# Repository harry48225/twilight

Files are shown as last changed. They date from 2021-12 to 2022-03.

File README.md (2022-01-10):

# ```twlight```

An automated roller blind opener. Using an esp32 runing micropython.

## ```twilight.local```
The esp32 serves a svelte webapp on ``` twilight.local```. See ```firmware/webapp```
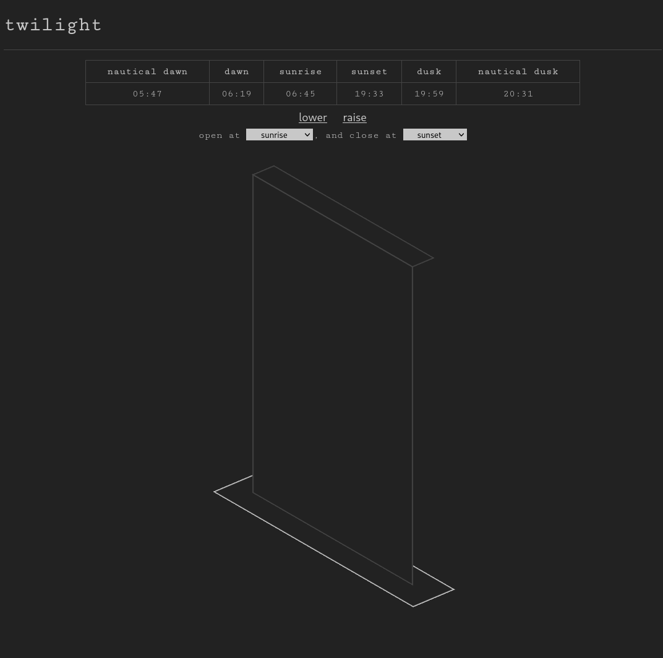
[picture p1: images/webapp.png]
webapp


## ```hardware```
A NEMA 17 stepper motor is used to move the blinds. It's connected to a 3d-printed gearbox ```cad/``` providing an ~1:5 reduction. It's driven by a DRV8825 stepper motor driver.
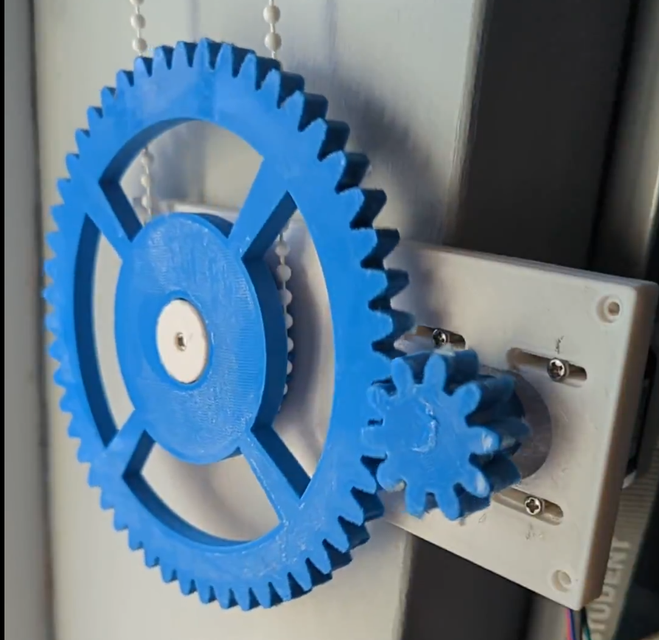
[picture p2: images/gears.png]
gears


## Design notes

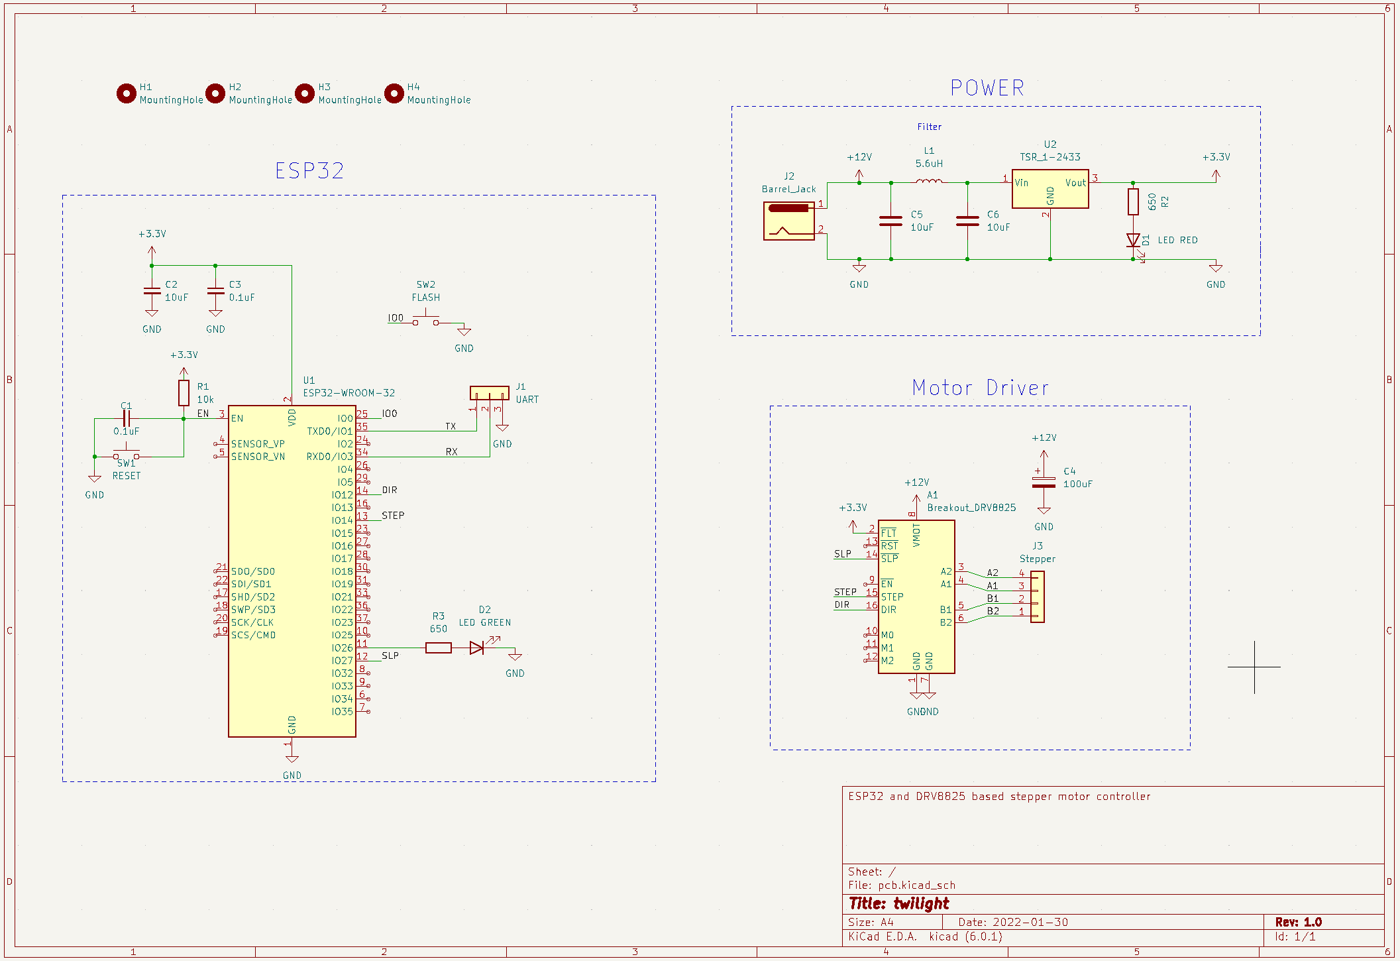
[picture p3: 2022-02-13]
pcb/pcb/schematic.png

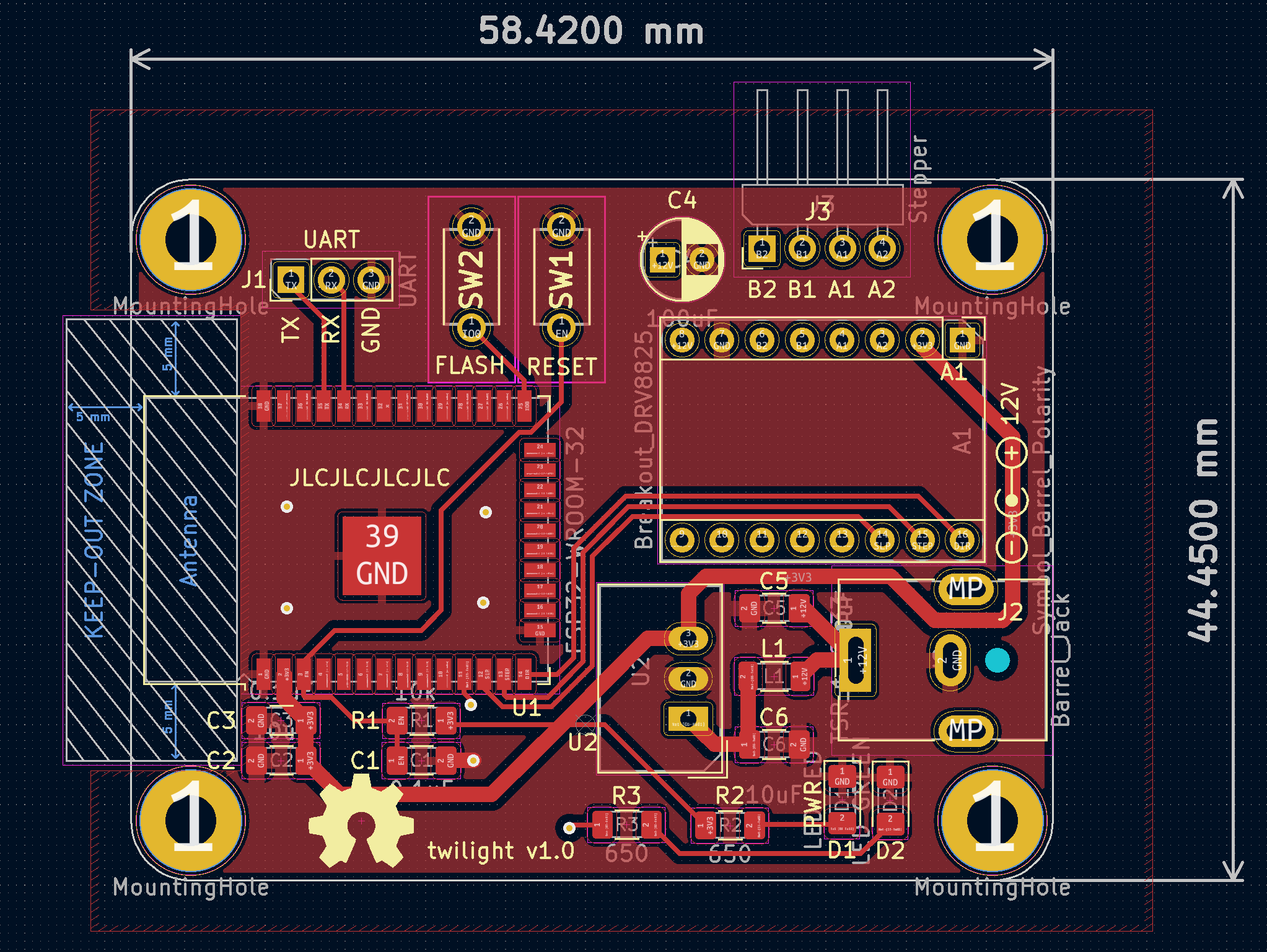
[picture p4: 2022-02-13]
pcb/pcb/pcbtop.png

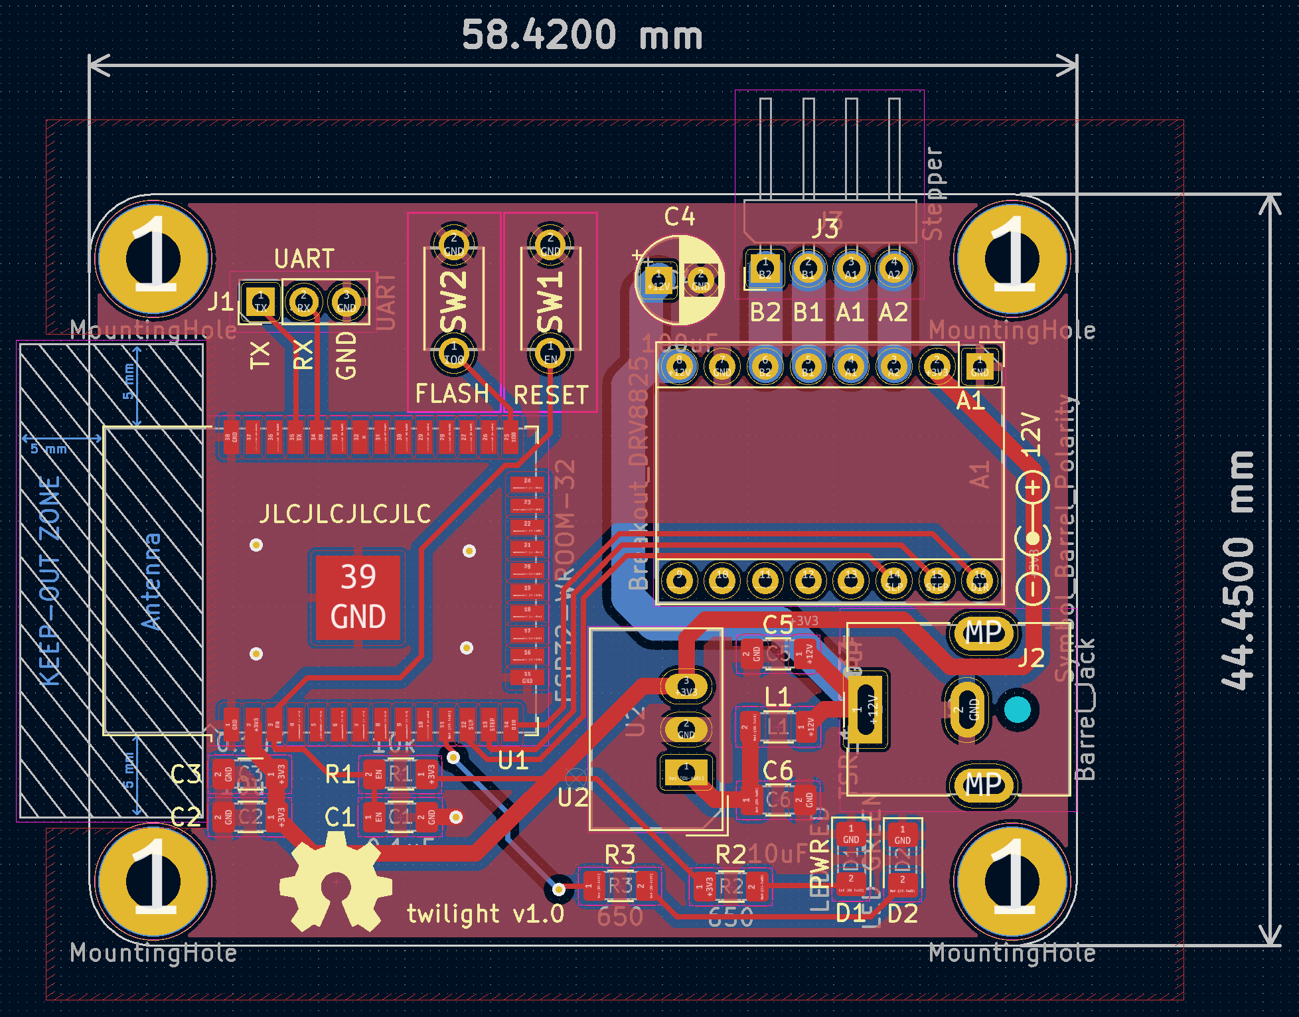
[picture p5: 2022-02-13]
pcb/pcb/fullpcb.png

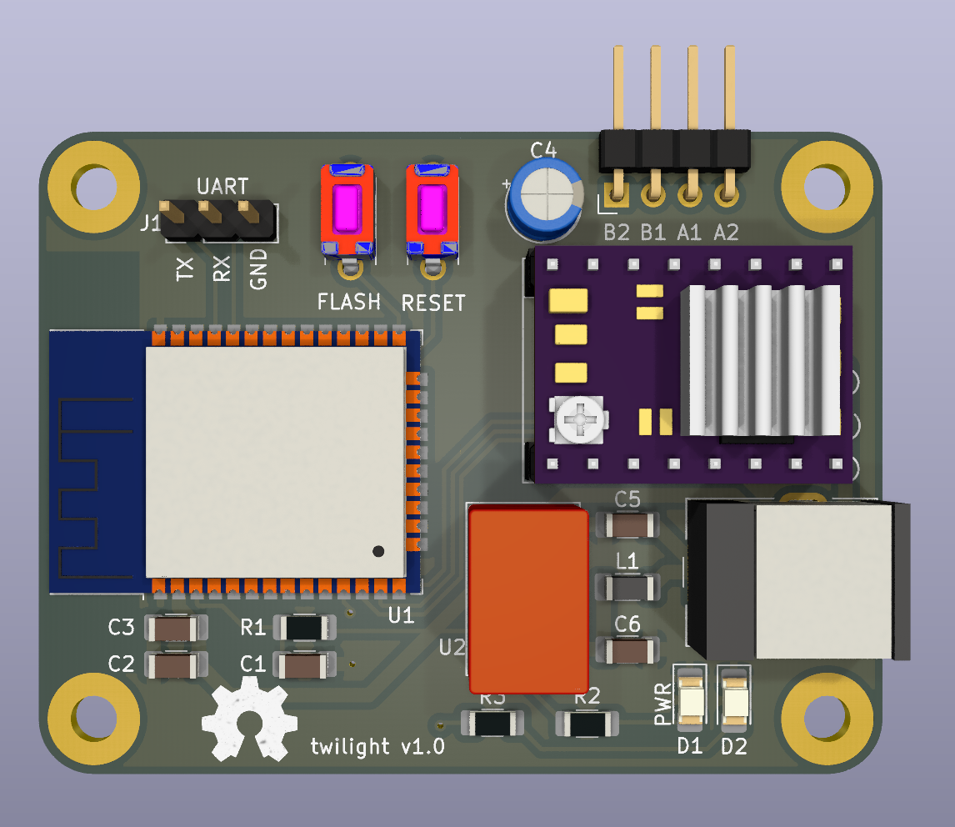
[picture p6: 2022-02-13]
pcb/pcb/3d render.png

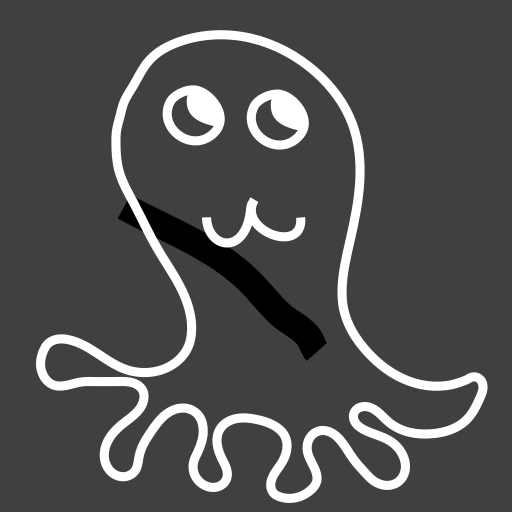
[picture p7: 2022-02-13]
pcb/octopus.png

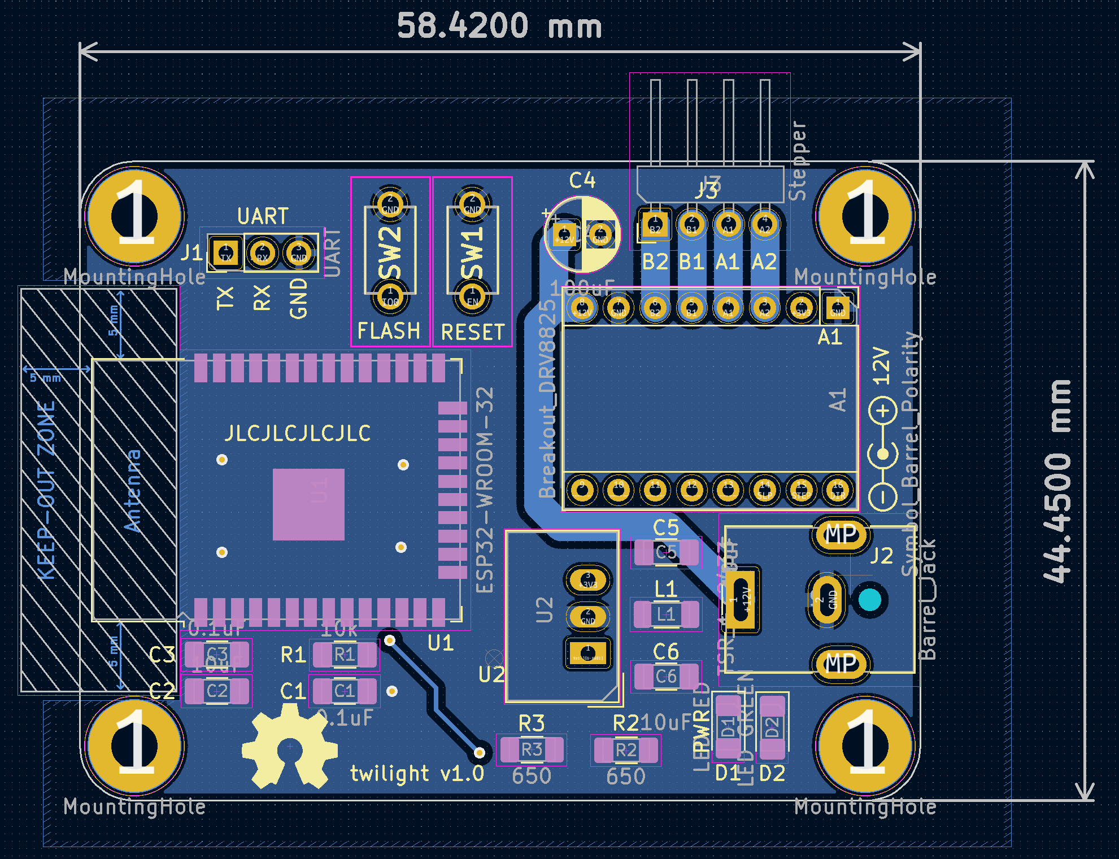
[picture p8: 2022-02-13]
pcb/pcb/pcbbottom.png

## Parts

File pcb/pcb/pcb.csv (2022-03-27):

Source: | /home/harry/Documents/twilight/pcb/pcb/pcb.kicad_sch
Date: | Fri 04 Mar 2022 14:39:49 GMT
Tool: | Eeschema (6.0.2)
Generator: | /usr/share/kicad/plugins/bom_csv_grouped_by_value_with_fp.py
Component Count: | 24
Ref | Qnty | Value | Cmp name | Footprint | Description | Vendor
A1, | 1 | Breakout_DRV8825 | Pololu_Breakout_DRV8825 | Module:Pololu_Breakout-16_15.2x20.3mm | Pololu Breakout Board, Stepper Driver DRV8825
C1, C3, | 2 | 0.1uF | C_Small | Capacitor_SMD:C_1206_3216Metric_Pad1.33x1.80mm_HandSolder | Unpolarized capacitor, small symbol
C2, C5, C6, | 3 | 10uF | C | Capacitor_SMD:C_1206_3216Metric_Pad1.33x1.80mm_HandSolder | Unpolarized capacitor
C4, | 1 | 100uF | C_Polarized | Capacitor_THT:CP_Radial_D5.0mm_P2.50mm | Polarized capacitor
D1, | 1 | LED RED | LED | LED_SMD:LED_1206_3216Metric_Pad1.42x1.75mm_HandSolder | Light emitting diode
D2, | 1 | LED GREEN | LED | LED_SMD:LED_1206_3216Metric_Pad1.42x1.75mm_HandSolder | Light emitting diode
H1, H3, | 2 | MountingHole | MountingHole | MountingHole:MountingHole_3.2mm_M3 | Mounting Hole without connection
H2, H4, | 2 | MountingHole | MountingHole | MountingHole:MountingHole_3.2mm_M3_Pad | Mounting Hole without connection
J1, | 1 | UART | Conn_01x03 | Connector_PinHeader_2.54mm:PinHeader_1x03_P2.54mm_Vertical | Generic connector, single row, 01x03, script generated (kicad-library-utils/schlib/autogen/connector/)
J2, | 1 | Barrel_Jack | Barrel_Jack | Connector_BarrelJack:BarrelJack_CUI_PJ-063AH_Horizontal | DC Barrel Jack
J3, | 1 | Stepper | Conn_01x04 | Connector_PinHeader_2.54mm:PinHeader_1x04_P2.54mm_Horizontal | Generic connector, single row, 01x04, script generated (kicad-library-utils/schlib/autogen/connector/)
L1, | 1 | 5.6uH | L | Inductor_SMD:L_TracoPower_TCK-141 | Inductor
R1, | 1 | 10k | R | Resistor_SMD:R_1206_3216Metric_Pad1.30x1.75mm_HandSolder | Resistor
R2, R3, | 2 | 650 | R | Resistor_SMD:R_1206_3216Metric_Pad1.30x1.75mm_HandSolder | Resistor
SW1, | 1 | RESET | SW_Push | buttons:PTS636SK43LFS | Push button switch, generic, two pins
SW2, | 1 | FLASH | SW_Push | buttons:PTS636SK43LFS | Push button switch, generic, two pins
U1, | 1 | ESP32-WROOM-32 | ESP32-WROOM-32 | RF_Module:ESP32-WROOM-32 | RF Module, ESP32-D0WDQ6 SoC, Wi-Fi 802.11b/g/n, Bluetooth, BLE, 32-bit, 2.7-3.6V, onboard antenna, SMD
U2, | 1 | TSR_1-2433 | TSR_1-2433 | Converter_DCDC:Converter_DCDC_TRACO_TSR-1_THT | 1A step-down regulator module, fixed 3.3V output voltage, 5-36V input voltage, -40°C to +85°C temperature range, TO-220 compatible LM78xx replacement

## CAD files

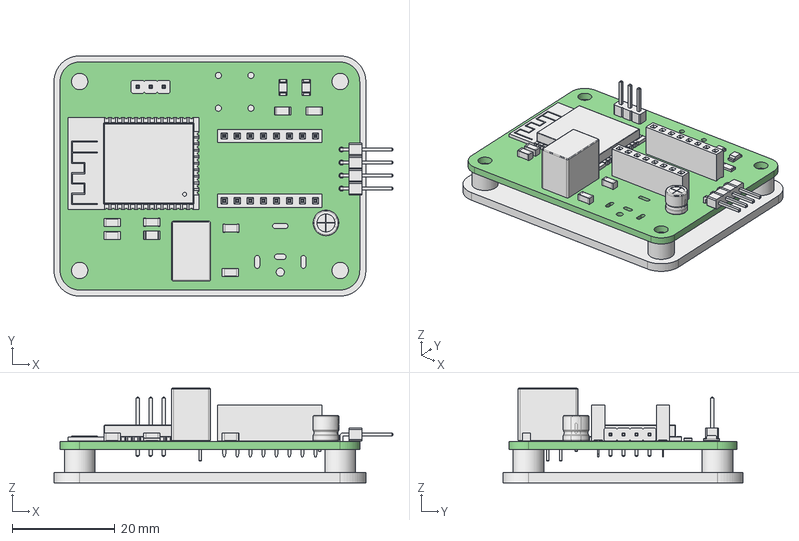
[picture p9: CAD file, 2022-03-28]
cad/pcb mount.FCStd
66.1 x 46.8 x 18.5 mm
pcb PCB

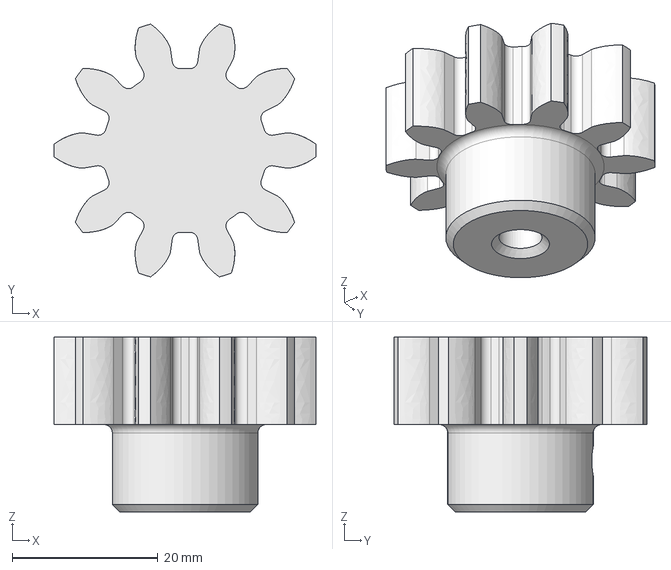
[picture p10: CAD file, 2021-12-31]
cad/small gear.FCStd
36.0 x 34.7 x 24.0 mm

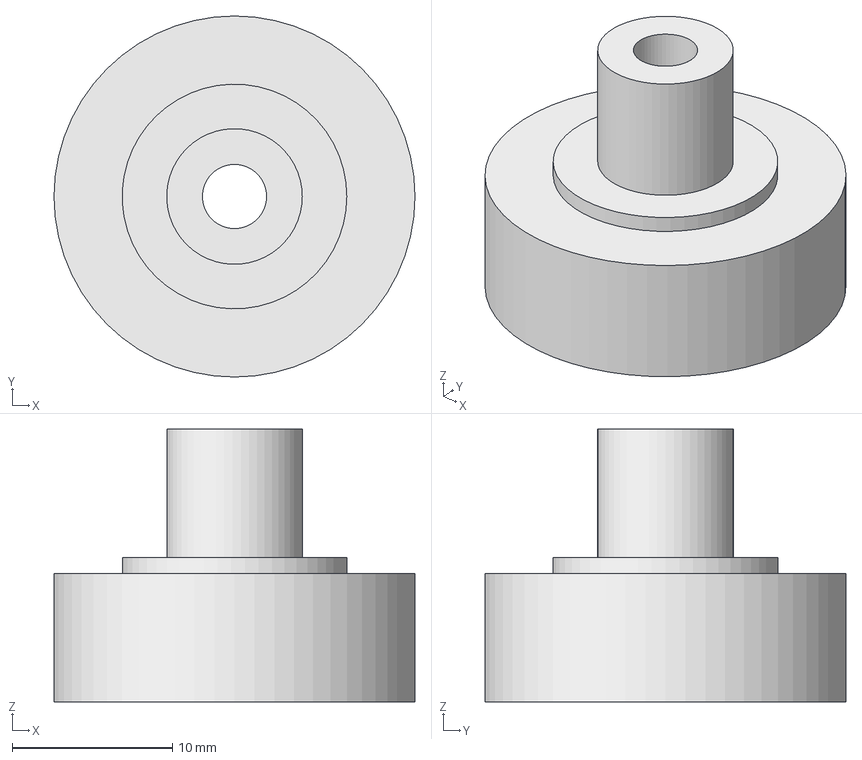
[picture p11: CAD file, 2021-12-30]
cad/large gear shaft.FCStd
22.5 x 22.5 x 17.0 mm

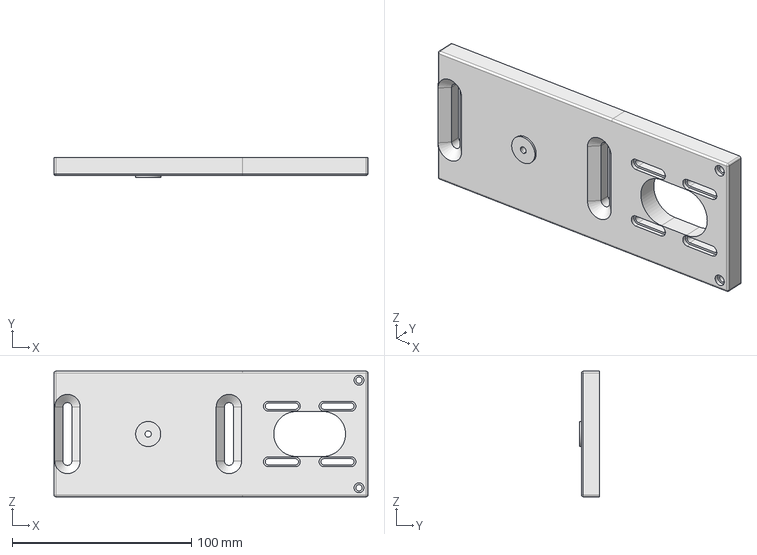
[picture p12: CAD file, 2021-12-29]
cad/wall plate.FCStd
175.0 x 11.0 x 70.0 mm

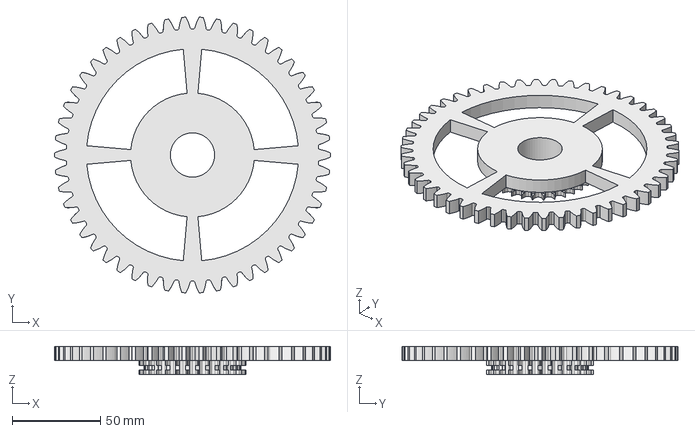
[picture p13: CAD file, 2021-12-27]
cad/blindGear.FCStd
156.0 x 155.8 x 16.0 mm

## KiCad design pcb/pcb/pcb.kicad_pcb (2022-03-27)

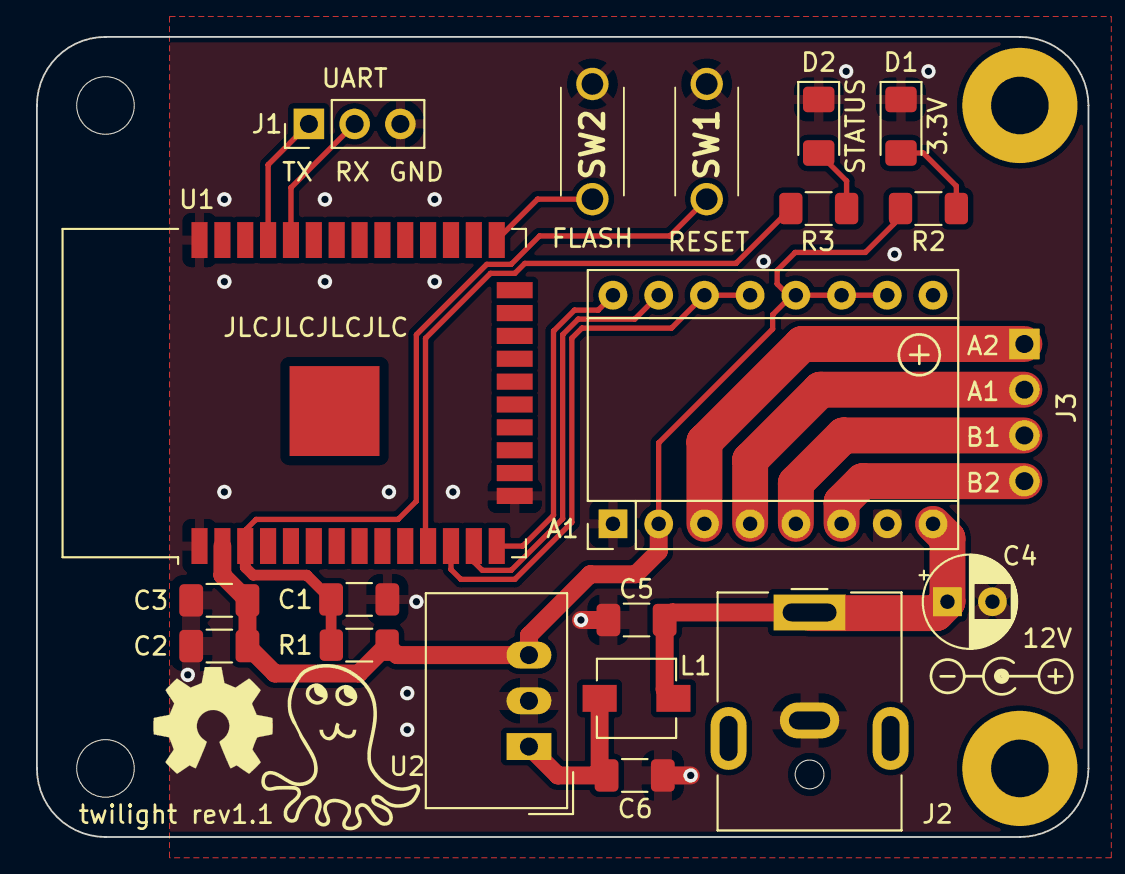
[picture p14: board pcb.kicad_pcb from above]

Board: 2 copper layers, 58.4 x 44.4 mm, 24 parts (0 on the bottom side), 18 nets.

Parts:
A1: Breakout_DRV8825; Pololu_Breakout-16_15.2x20.3mm
C1, C3: 0.1uF; C_1206_3216Metric_Pad1.33x1.80mm_HandSolder
C2, C5, C6: 10uF; C_1206_3216Metric_Pad1.33x1.80mm_HandSolder
C4: 100uF; CP_Radial_D5.0mm_P2.50mm
D1: LED RED; LED_1206_3216Metric_Pad1.42x1.75mm_HandSolder
D2: LED GREEN; LED_1206_3216Metric_Pad1.42x1.75mm_HandSolder
H1, H3: MountingHole; MountingHole_3.2mm_M3
H2, H4: MountingHole; MountingHole_3.2mm_M3_Pad
J1: UART; PinHeader_1x03_P2.54mm_Vertical
J2: Barrel_Jack; BarrelJack_CUI_PJ-063AH_Horizontal
J3: Stepper; PinHeader_1x04_P2.54mm_Horizontal
L1: 5.6uH; L_TracoPower_TCK-141
R1: 10k; R_1206_3216Metric_Pad1.30x1.75mm_HandSolder
R2, R3: 680; R_1206_3216Metric_Pad1.30x1.75mm_HandSolder
SW1: RESET; PTS636SK43LFS
SW2: FLASH; PTS636SK43LFS
U1: ESP32-WROOM-32
U2: TSR_1-2433; Converter_DCDC_TRACO_TSR-1_THT

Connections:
+3V3: A1.2 (~FLT), A1.10 (M0), A1.11 (M1), A1.12 (M2), C2.1, C3.1, R1.1, R2.1, U1.2 (VDD), U2.3 (Vout)
+12V: A1.8 (VMOT), C4.1, C5.1, J2.1, L1.1
/A1: A1.4 (A1), J3.2
/A2: A1.3 (A2), J3.1
/B1: A1.5 (B1), J3.3
/B2: A1.6 (B2), J3.4
/DIR: A1.16 (DIR), U1.14 (IO12)
/EN: C1.1, R1.2, SW1.1, U1.3 (EN)
/IO0: SW2.1, U1.25 (IO0)
/RX: J1.2, U1.34 (RXD0/IO3)
/SLP: A1.13 (~RST), A1.14 (~SLP), U1.12 (IO27)
/STEP: A1.15 (STEP), U1.13 (IO14)
/TX: J1.1, U1.35 (TXD0/IO1)
GND: A1.1 (GND), A1.7 (GND), C1.2, C2.2, C3.2, C4.2, C5.2, C6.2, D1.1 (K), D2.1 (K), J1.3, J2.2, SW1.2, SW2.2, U1.1 (GND), U1.15 (GND), U1.38 (GND), U1.39 (GND), U2.2 (GND)
unnamed: C6.1, L1.2, U2.1 (Vin)
unnamed: D1.2 (A), R2.2
unnamed: D2.2 (A), R3.2
unnamed: R3.1, U1.11 (IO26)

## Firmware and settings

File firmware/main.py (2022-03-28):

import network
import credentials
from machine import freq, Pin
from time import sleep, localtime
from microdot_asyncio import Microdot, Response, send_file
import uasyncio
import ntptime
import suncalc
from motor import Motor_Controller
from machine import WDT

LAT = 53.576866
LONG = -2.428219

HOSTNAME = "twilight"

def get_wlan():
  wlan = network.WLAN(network.STA_IF)
  wlan.active(True)
  wlan.config(dhcp_hostname=HOSTNAME)
  wlan.ifconfig(('192.168.0.201', '255.255.255.0', '192.168.0.1', '8.8.8.8'))
  wlan.connect(credentials.SSID, credentials.PASSWORD)

  print(f"connecting to wlan {credentials.SSID}, with password: {credentials.PASSWORD}")
  status_LED.off()
  while not wlan.isconnected():
    print(".", end="")
    status_LED.on()
    sleep(0.5)
    status_LED.off()
    sleep(0.5)
  print("connected!")
  status_LED.on()
  return wlan

async def set_clock():
  print("trying to get ntp time")
  while True:
    try:
      ntptime.settime()
      print("successfully synced with ntp time")
      break
    except:
      print("error aquiring time, retrying")
      await uasyncio.sleep(1)

async def feed_watchdog():
  while True:
    status_LED.off()
    if wlan.isconnected():
      wdt.feed()
      await uasyncio.sleep_ms(100)
      status_LED.on()
      
    await uasyncio.sleep(2)

    

app = Microdot()

@app.route('/')
async def index(request):
  return send_file("public/index.html")

@app.route('/<re:([^a]|a[^p]|ap[^i]).*:path>')
async def not_api(request, path):
  # not an api endpoint so serve the public file
  try:
    # Kinda a big security risk... should probably sanitise these
    response = send_file(f"public/{path}")
  except:
    response = send_file("public/index.html")

  return response

@app.route('api/ha/switch', methods=['GET','POST'])
def home_assistant_switch(request):
  global motor
  if request.method == 'POST':
    state = request.body.decode('utf-8')
    print(state)
    if state == "ON":
      motor.lower_blind()
      print("LOWERING BLIND")
    elif state == "OFF":
      motor.raise_blind()
    return Response(status_code=200)
  elif request.method == 'GET':
    height = motor.get_normalised_height()
    if height >= 1:
      state = 'ON'
    else:
      state = 'OFF'
    print(f'current state: {state}')
    return Response(status_code=200, body=state)

@app.route('api/lower_blind')
def lower_blind(request):
  if (motor.running):
    return Response(status_code=503) # Service unavailable code
  else:
    motor.lower_blind()
    return Response(body={'height': motor.get_normalised_height()})

@app.route('api/raise_blind')
def raise_blind(request):
  if (motor.running):
    return Response(status_code=503) # Service unavailable code
  else:
    motor.raise_blind()
    return Response(body={'height': motor.get_normalised_height()})

@app.route('api/current_time')
async def current_time(request):
  return str(localtime())

@app.route('api/normalised_height')
async def normalised_height(request):
  return Response(body={'height': motor.get_normalised_height()})

@app.route('api/sun_times')
async def sun_times(request):
  times = suncalc.getTimes(localtime(), LAT, LONG)
  return Response(body=times)

wdt = WDT(timeout=5000) # Watchdog with timeout of 5 seconds
motor = Motor_Controller(wdt)

status_LED = Pin(26, Pin.OUT)

freq(240_000_000) # Set the clock speed to maximum
wlan = get_wlan()
uasyncio.create_task(set_clock())
uasyncio.create_task(feed_watchdog())
uasyncio.create_task(app.start_server(debug=True, port=80))
uasyncio.get_event_loop().run_forever()

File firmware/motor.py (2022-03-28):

from machine import Pin
import uasyncio
from time import sleep

class Motor_Controller():
  DIRECTION_UP = 1
  DIRECTION_DOWN = 0
  MOTOR_DELAY = 0.0005 # In seconds
  LOWERED_POSITION = 170_000 #170_000 is for 1/32 step  Good for highest microstepping resolution
  MOTOR_FILE = "motor_position.txt"
  WATCHDOG_THRESHOLD = 2 / MOTOR_DELAY
  
  def __init__(self, wdt):
    self.stepPin = Pin(14, Pin.OUT)
    self.direction = Pin(12, Pin.OUT) # on is up, off is down
    self.motor = Pin(27, Pin.OUT) # Connected to the sleep pin
    self.motor.off()
    self.motor_position: int = self.load_saved_position()
    self.running = False
    self.wdt = wdt
    
  def get_normalised_height(self):
    return float(self.motor_position) / float(self.LOWERED_POSITION)

  def load_saved_position(self)->int:
    motor_position = 0
    try:
      with open(self.MOTOR_FILE, "r") as f:
        motor_position = int(f.read())  

      print(f"Loaded motor position of {motor_position}")
    except:
      print("Motor position file doesn't exist / is corrupted :(, creating it!")
      with open(self.MOTOR_FILE, "w") as f:
        f.write(str(motor_position))
      
    return motor_position

  def set_direction_up(self):
    self.direction.on()

  def set_direction_down(self):
    self.direction.off()

  def step(self):
    '''steps the motor in the current direction, note: the motor must be turned on'''
    self.stepPin.on()
    sleep(self.MOTOR_DELAY)
    self.stepPin.off()
    if self.direction.value() == self.DIRECTION_UP:
      self.motor_position -= 1
    else:
      self.motor_position += 1

  def save_position(self):
    '''saves the current motor position to file'''
    with open(self.MOTOR_FILE, 'w') as f:
      f.write(str(self.motor_position))

  def lower_blind(self):
    self.direction.value(self.DIRECTION_DOWN)
    self.motor.on()
    print("lowering blind")
    self.running = True
    watchdog_counter = 0
    while self.motor_position < self.LOWERED_POSITION:
      self.step()
      sleep(self.MOTOR_DELAY)
      # This async so we should feed the watchdog
      if watchdog_counter > self.WATCHDOG_THRESHOLD:
        self.wdt.feed()
        watchdog_counter = 0
      watchdog_counter+=1

    self.motor.off()
    self.save_position()
    print("blind lowered!")
    self.running = False

  def raise_blind(self):
    self.direction.value(self.DIRECTION_UP)
    self.motor.on()
    self.running = True
    print("raising blind")
    watchdog_counter = 0
    while self.motor_position > 0:
      self.step()
      sleep(self.MOTOR_DELAY)
      if watchdog_counter > self.WATCHDOG_THRESHOLD:
        self.wdt.feed()
        watchdog_counter = 0
      watchdog_counter+=1

    self.motor.off()
    self.save_position()
    print("blind raised!")
    self.running = False

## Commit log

2021-12-23 basic sprocket
    [blindGear.FCStd]
2021-12-26 Tweak large gear and create small gear
    [blindGear-Body.stl, blindGear.FCStd, blindGear2-Body.stl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]
2021-12-26 Create wall plate
    [wall plate.FCStd]
2021-12-26 update git ignore
    [blindGear-Body.stl, blindGear2-Body.stl, small gear-Body.stl]
2021-12-27 Updatedwall plate to include motor and basic sketch
    [blindGear2.FCStd, small gear.FCStd, wall motor mount.FCStd]
2021-12-28 resize small gear
    [small gear.FCStd, wall motor mount.FCStd]
2021-12-28 increase gear size
    [small gear.FCStd]
2021-12-29 add x stepper slots, delete shaft, add captive nut
    [wall plate.FCStd]
2021-12-29 add fillet
    [wall plate.FCStd]
2021-12-29 Increase gear distance
    [wall plate.FCStd]
2021-12-29 Make make for large gear
    [large gear shaft.FCStd, wall plate.FCStd]
2021-12-29 increase shaft diameter
    [large gear shaft.FCStd]
2021-12-30 Tweak sizes
    [large gear shaft.FCStd]
2021-12-30 Inital draft
    [small gear.FCStd]
2021-12-31 Add captive fixing nut
    [small gear.FCStd]
2021-12-31 Add captive nut
    [small gear.FCStd]
2021-12-31 Remove old parts
    [blindGear.FCStd, blindGear2.FCStd, wall motor mount.FCStd]
2022-01-02 Add lower and raise buttons
2022-01-02 Switch to mono font
2022-01-03 Add skeleton motor controller class
2022-01-03 fix ntp timeout error
    [main.py]
2022-01-03 Add open and close methods to motor class
2022-01-03 Make raise and lower buttons functional
2022-01-04 double motor speed
2022-01-06 Add power and motor driver
    [pcb.kicad_pcb, pcb.kicad_sch]
2022-01-06 Add esp32
    [pcb.kicad_sch]
2022-01-06 basic pcb layout
    [pcb.kicad_pcb, pcb.kicad_sch]
2022-01-06 Route pcb
    [pcb.kicad_pcb, pcb.kicad_sch]
2022-01-06 Add silkscreen
    [pcb.kicad_pcb]
2022-01-07 motor refactor
2022-01-07 Make motor loop blocking, vastly increasing speed
2022-01-07 Tweak motor speed
2022-01-07 Switch to 1/32 step mode
2022-01-10 Add gears photo
2022-01-23 add reset and boot buttons
    [pcb.kicad_pcb]
2022-01-23 route traces
    [pcb.kicad_pcb, pcb.kicad_sch]
2022-01-23 Add power led
    [pcb.kicad_pcb]
2022-01-23 add copper pours
    [pcb.kicad_pcb, pcb.kicad_sch]
2022-01-23 tweaks from reddit wiki
    [pcb.kicad_pcb, pcb.kicad_sch]
2022-01-27 add activity led and general tidy
    [pcb.kicad_pcb, pcb.kicad_sch]
2022-01-30 general tweaks
    [pcb.kicad_pcb, pcb.kicad_sch]
2022-01-30 tidy schematic
    [pcb.kicad_sch]
2022-01-30 Reroute pcb
    [pcb.kicad_pcb, pcb.kicad_sch]
2022-02-01 third reddit revision
    [pcb.kicad_pcb, pcb.kicad_sch]
2022-02-03 change minimum via size and tweak traces
    [pcb.kicad_pcb]
2022-02-04 fix mounting hole footprint in schematic
    [pcb.kicad_pcb, pcb.kicad_sch]
2022-02-04 add more silkscreen
    [pcb.kicad_pcb]
2022-02-11 small layout tweaks
    [pcb.kicad_pcb]
2022-02-11 add octopus icon
    [pcb.kicad_pcb]
2022-02-11 generate gerbers and 3d model
    [pcb-B_Cu.gbl, pcb-B_Mask.gbs, pcb-B_Paste.gbp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]
2022-03-04 change resistor values to more standard
    [pcb.csv, pcb.kicad_sch]
2022-03-27 Change pin assignments to match PCB
2022-03-27 Update pins to match pcb
2022-03-27 Add watchdog timer
2022-03-27 Feed watchdog during motor moves
2022-03-27 Update pcb to fix bugs
    [pcb.kicad_pcb, pcb.kicad_sch]
2022-03-27 Optimise routing
    [pcb.kicad_pcb, pcb.kicad_sch]
2022-03-28 pcb wall mount
    [pcb mount.FCStd]
